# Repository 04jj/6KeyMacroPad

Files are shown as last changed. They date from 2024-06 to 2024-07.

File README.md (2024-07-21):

# 6KeyMacroPad

Feel free to use/modify the files to make your own macropad! ai03's keyboard design wiki is very helpful, I highly recommend reading it.
I am including all PCB files and CAD files for the case. 

Some pics (I 3D printed and sanded the keycaps by hand so they are not the most even/nice):

 

# Specs
* In-key RGB lighting 
* Hot-swappable
* Atmega32U2 MCU
* USB-C Port
* Acrylic stack case
* QMK/VIA compatible

# Firmware/QMK/VIA support
Use zadig to install the WinUSB drivers onto the Atmega32u2
Use qmk msys to compile the .hex file to flash onto the MCU
Use qmk toolbox to flash the MCU (to turn the MCU into bootloader mode, press the reset switch on the back of the PCB)
  - There are default and via keymaps (I recommend using the via one so you can easily map macros/your own keys/adjust lighting easily)

# PCB/Build Files
See folder named PCB Gerber files to get the required files to order the PCB. I did not order PCBA but you can do so if you don't want to hand-solder by referencing the BOM and PCB/Schematic files.

 

For the case, I provided the .step files in the folder named Case Step Files for each layer of the acrylic stack. I used M2 Screws with some washers and spacers to secure everything together (w/o washers M3 screws and spacers should work fine - might require a little bit of sanding).

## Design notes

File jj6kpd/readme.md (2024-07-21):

# jj6kpd

jj6kpd

*A short description of the keyboard/project*

* Keyboard Maintainer: [jj](https://github.com/04jj)
* Hardware Supported: jjkpd pcb or any 2x3 ortho config pcb
* Hardware Availability: from my github page

Make example for this keyboard (after setting up your build environment):

    make jj6kpd:default

* For via support make sure to compile via keymap (to use via go into the design tab and upload via.json to start editing)

Flashing example for this keyboard:

    make jj6kpd:default:flash

See the [build environment setup](https://docs.qmk.fm/#/getting_started_build_tools) and the [make instructions](https://docs.qmk.fm/#/getting_started_make_guide) for more information. Brand new to QMK? Start with our [Complete Newbs Guide](https://docs.qmk.fm/#/newbs).

## Bootloader

Enter the bootloader:

* **Physical reset button**: Briefly press the button on the back of the PCB

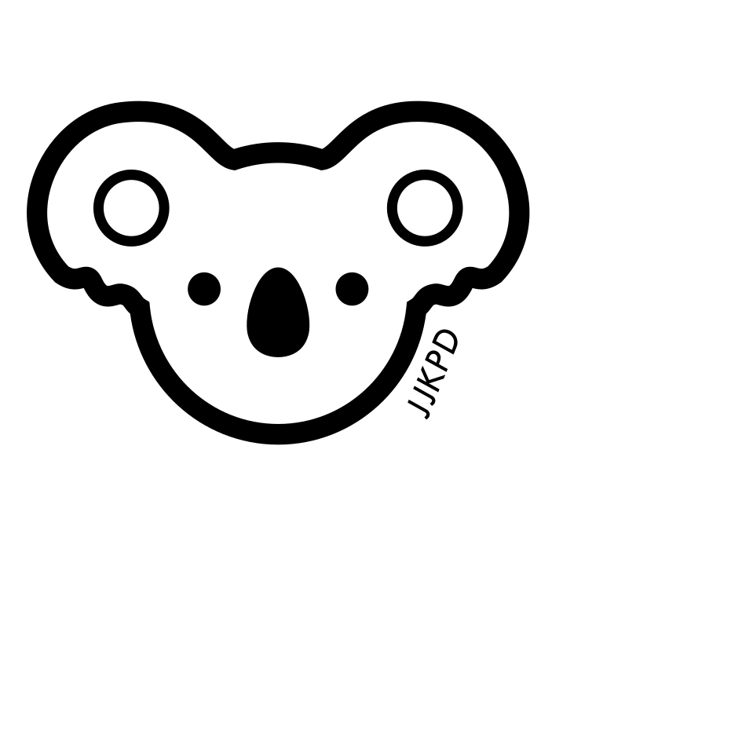
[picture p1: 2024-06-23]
.svg2shenzhen-cache/images/F.SilkS_layer1.png

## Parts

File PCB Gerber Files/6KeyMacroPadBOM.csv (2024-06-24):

Id | Designator | Footprint | Quantity | Designation | Supplier and ref
1 | SW1 | SW_SPST_SKQG_WithStem | 1 | SW_Push
2 | D10,D8,D11,D9,D12,D13 | MX_SK6812MINI-E | 6 | SK6812MINI-E
3 | S6,S2,S5,S3,S4,S1 | Hotswap_MX_1.00u | 6 | Keyswitch
4 | C2,C1 | C_0805_2012Metric | 2 | 22 pF
5 | C5,C4,C6 | C_0805_2012Metric | 3 | 0.1 uF
6 | R3,R4 | R_0805_2012Metric | 2 | 10k
7 | R2,R1 | R_0805_2012Metric | 2 | 22
8 | D7 | SOT-143 | 1 | PRTR5V0U2X
9 | C8,C13,C12,C10,C11,C9 | C_0805_2012Metric | 6 | 100 nF
10 | C3 | C_0805_2012Metric | 1 | 1 uF
11 | R6,R5 | R_0805_2012Metric | 2 | 5.1k
12 | FB1 | L_0805_2012Metric_Pad1.15x1.40mm_HandSolder | 1 | 60@100MHz
13 | Y1 | Crystal_SMD_3225-4Pin_3.2x2.5mm_HandSoldering | 1 | 16 MHz
14 | D4,D5,D3,D6,D1,D2 | D_SOD-123 | 6 | Diode
15 | F1 | Fuse_1206_3216Metric | 1 | 500m
16 | USB1 | HRO-TYPE-C-31-M-12-HandSoldering | 1 | HRO-TYPE-C-31-M-12
17 | C7 | C_0805_2012Metric | 1 | 10 uF
18 | U2 | TQFP-32_7x7mm_P0.8mm | 1 | ATmega32U2-A
19 | R7 | R_0805_2012Metric | 1 | 500
20 | Ref** | jjkpdlogo | 1 | Val**

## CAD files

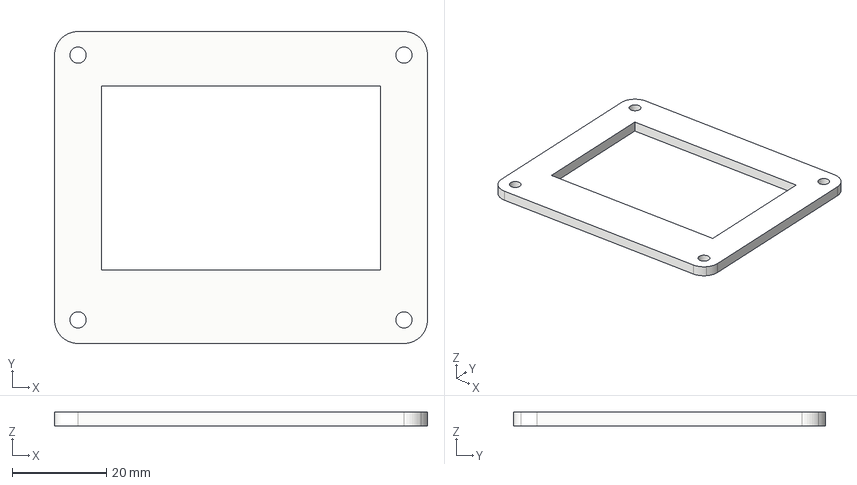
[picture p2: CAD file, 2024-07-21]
Case Step Files/TopPCBCase.step
79.2 x 66.2 x 3.00 mm

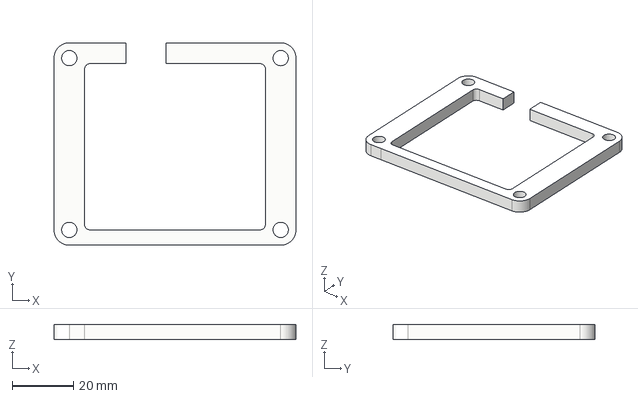
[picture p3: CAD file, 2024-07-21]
Case Step Files/MiddlePCBCase1.step
79.2 x 66.2 x 5.00 mm

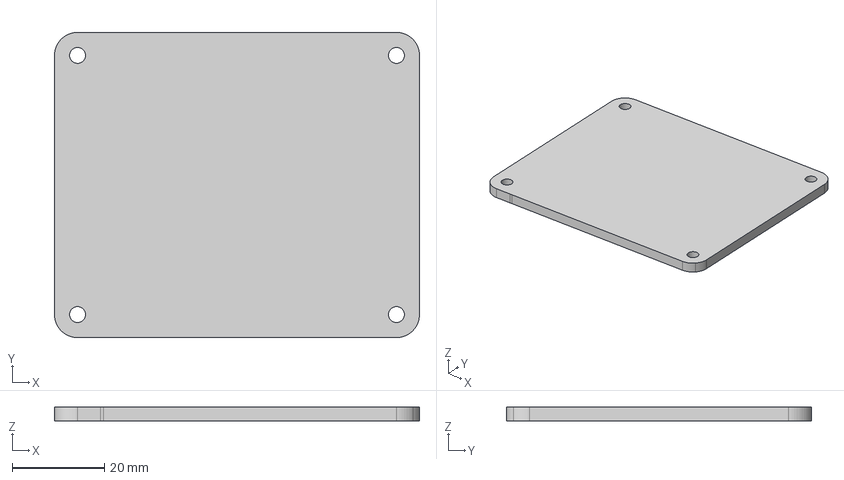
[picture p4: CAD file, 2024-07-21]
Case Step Files/PCBCaseBottom.step
79.2 x 66.2 x 3.00 mm

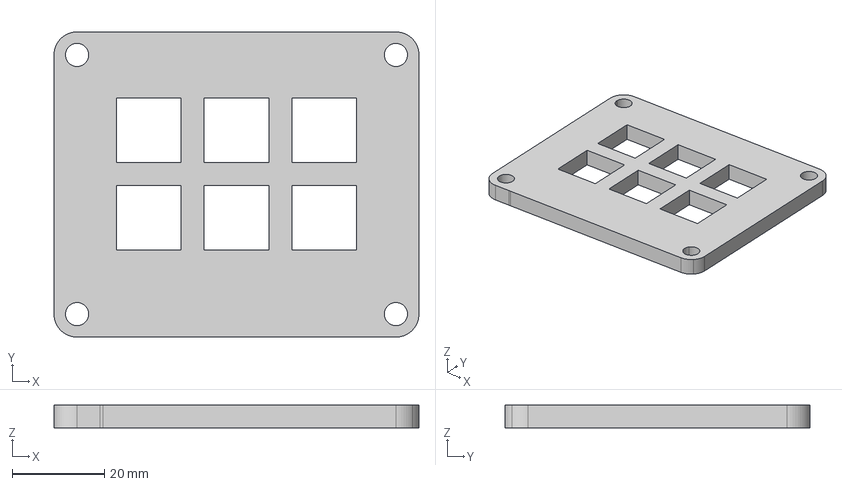
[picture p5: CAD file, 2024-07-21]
Case Step Files/MiddlePCBCase2.step
79.2 x 66.2 x 4.95 mm

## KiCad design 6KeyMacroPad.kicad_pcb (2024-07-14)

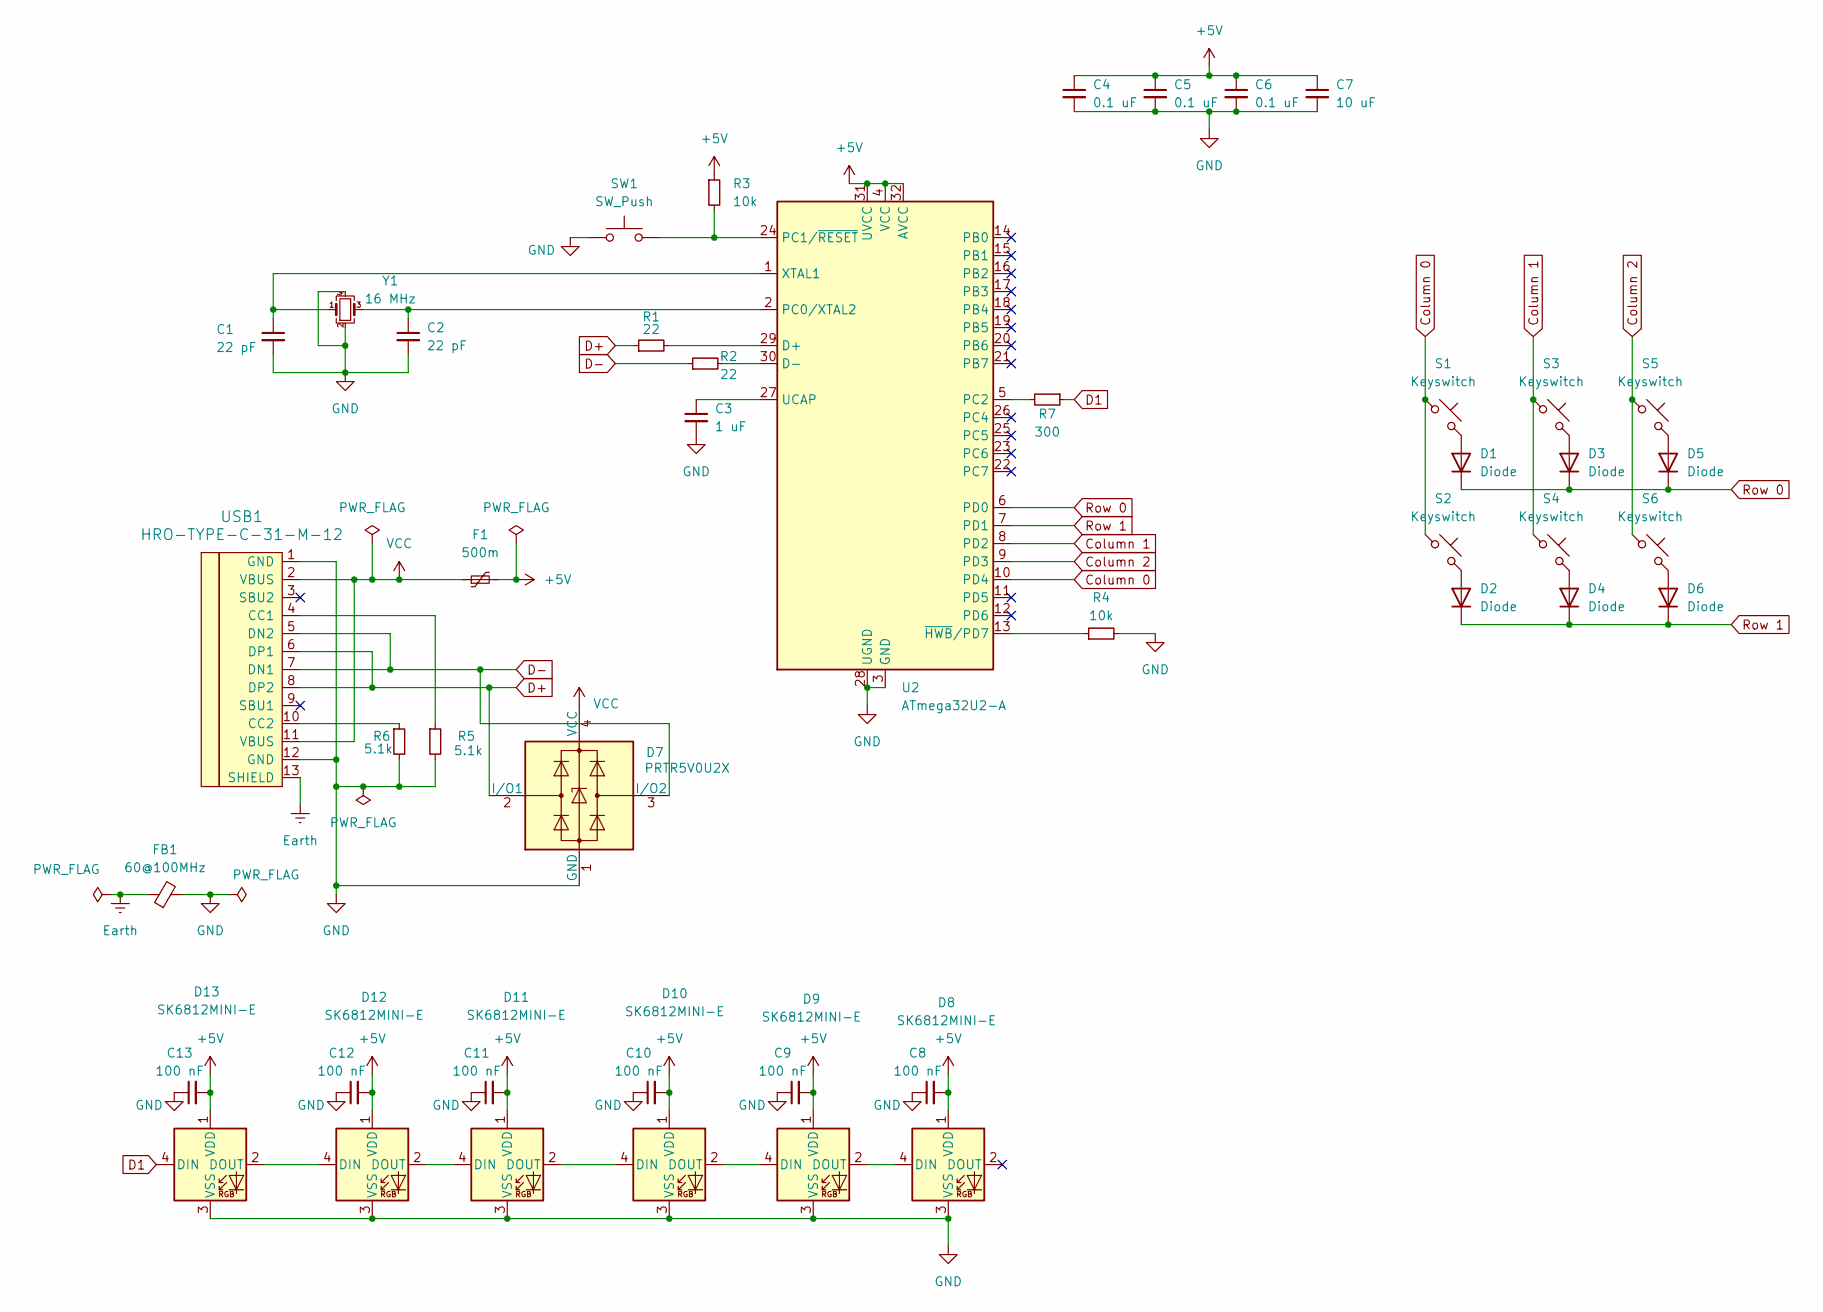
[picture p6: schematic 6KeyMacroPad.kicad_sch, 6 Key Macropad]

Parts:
C1, C2: 22 pF; C_0805_2012Metric
C3: 1 uF; C_0805_2012Metric
C4, C5, C6: 0.1 uF; C_0805_2012Metric
C7: 10 uF; C_0805_2012Metric
C8, C9, C10, C11, C12, C13: 100 nF; C_0805_2012Metric
D1, D2, D3, D4, D5, D6: Diode; D_SOD-123
D7: PRTR5V0U2X; SOT-143
D8, D9, D10, D11, D12, D13: SK6812MINI-E; MX_SK6812MINI-E
F1: 500m; Fuse_1206_3216Metric
FB1: 60@100MHz; L_0805_2012Metric_Pad1.15x1.40mm_HandSolder
R1, R2: 22; R_0805_2012Metric
R3, R4: 10k; R_0805_2012Metric
R5, R6: 5.1k; R_0805_2012Metric
R7: 300; R_0805_2012Metric
S1, S2, S3, S4, S5, S6: Keyswitch; Hotswap_MX_1.00u
SW1: SW_Push; SW_SPST_SKQG_WithStem
U2: ATmega32U2-A; TQFP-32_7x7mm_P0.8mm
USB1: HRO-TYPE-C-31-M-12; HRO-TYPE-C-31-M-12-HandSoldering
Y1: 16 MHz; Crystal_SMD_3225-4Pin_3.2x2.5mm_HandSoldering

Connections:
+5V: C4.1, C5.1, C6.1, C7.1, C8.2, C9.2, C10.2, C11.2, C12.2, C13.2, D8.1 (VDD), D9.1 (VDD), D10.1 (VDD), D11.1 (VDD), D12.1 (VDD), D13.1 (VDD), F1.2, R3.1, U2.4 (VCC), U2.31 (UVCC), U2.32 (AVCC)
Column 0: S1.1, S2.1, U2.10 (PD4)
Column 1: S3.1, S4.1, U2.8 (PD2)
Column 2: S5.1, S6.1, U2.9 (PD3)
D1: D13.4 (DIN), R7.1
D+: D7.2 (I/O1), R1.1, USB1.6 (DP1), USB1.8 (DP2)
D-: D7.3 (I/O2), R2.1, USB1.5 (DN2), USB1.7 (DN1)
Earth: FB1.1, USB1.13 (SHIELD)
GND: C1.2, C2.2, C3.2, C4.2, C5.2, C6.2, C7.2, C8.1, C9.1, C10.1, C11.1, C12.1, C13.1, D7.1 (GND), D8.3 (VSS), D9.3 (VSS), D10.3 (VSS), D11.3 (VSS), D12.3 (VSS), D13.3 (VSS), FB1.2, R4.2, R5.2, R6.2, SW1.1, U2.3 (GND), U2.28 (UGND), USB1.1 (GND), USB1.12 (GND), Y1.2, Y1.4
unnamed: D1.2 (A), S1.2
unnamed: D2.2 (A), S2.2
unnamed: D3.2 (A), S3.2
unnamed: D4.2 (A), S4.2
unnamed: D5.2 (A), S5.2
unnamed: D6.2 (A), S6.2
unnamed: D8.4 (DIN), D9.2 (DOUT)
unnamed: D10.4 (DIN), D11.2 (DOUT)
unnamed: D9.4 (DIN), D10.2 (DOUT)
unnamed: D11.4 (DIN), D12.2 (DOUT)
unnamed: D12.4 (DIN), D13.2 (DOUT)
unnamed: R1.2, U2.29 (D+)
unnamed: R2.2, U2.30 (D-)
unnamed: C2.1, U2.2 (PC0/XTAL2), Y1.3
unnamed: R3.2, SW1.2, U2.24 (PC1/~RESET)
unnamed: R7.2, U2.5 (PC2)
unnamed: C3.1, U2.27 (UCAP)
unnamed: C1.1, U2.1 (XTAL1), Y1.1
unnamed: R4.1, U2.13 (~HWB/PD7)
unnamed: R5.1, USB1.4 (CC1)
unnamed: R6.1, USB1.10 (CC2)
Row 0: D1.1 (K), D3.1 (K), D5.1 (K), U2.6 (PD0)
Row 1: D2.1 (K), D4.1 (K), D6.1 (K), U2.7 (PD1)
VCC: D7.4 (VCC), F1.1, USB1.2 (VBUS), USB1.11 (VBUS)

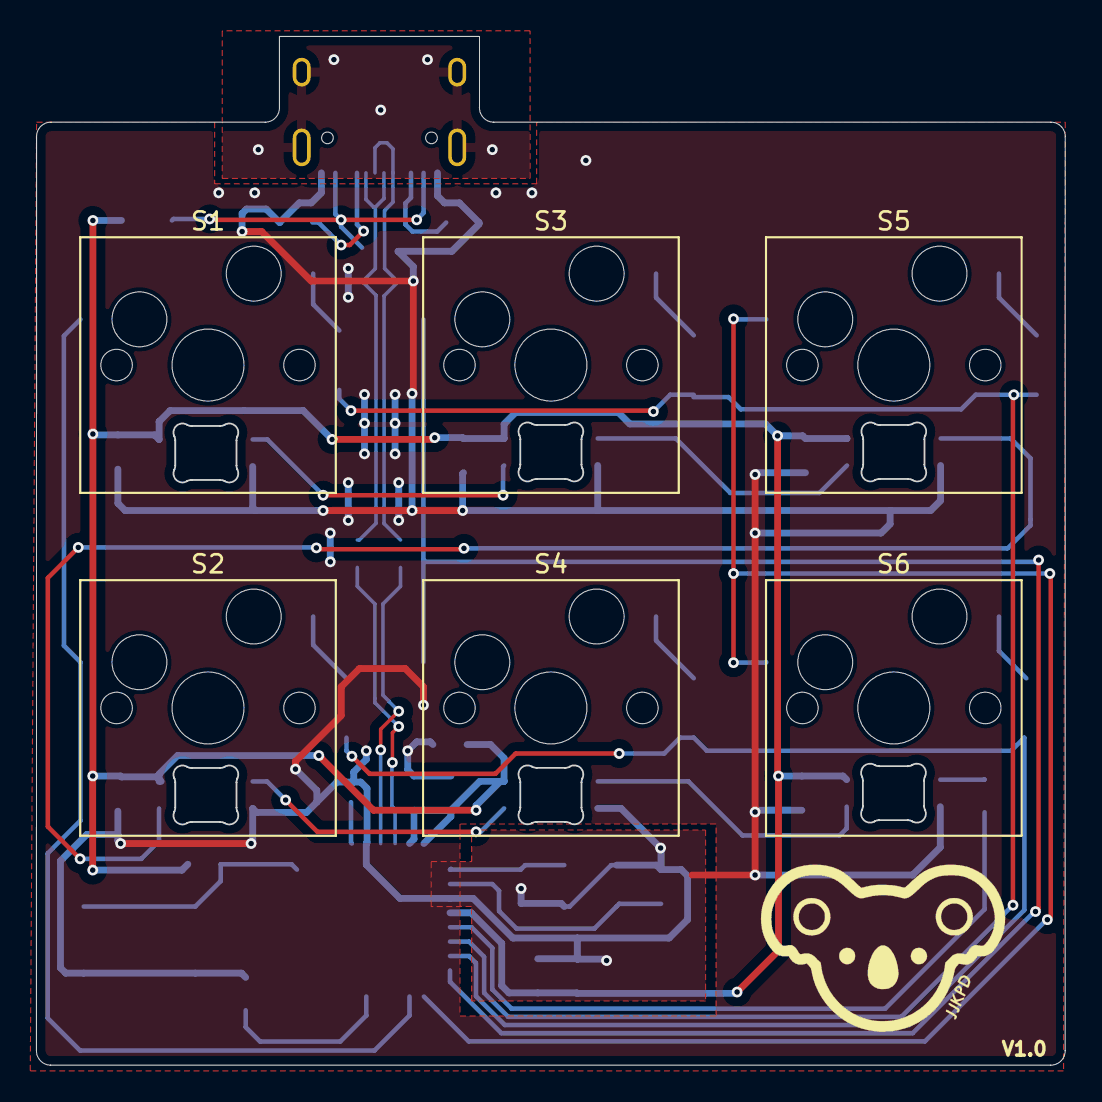
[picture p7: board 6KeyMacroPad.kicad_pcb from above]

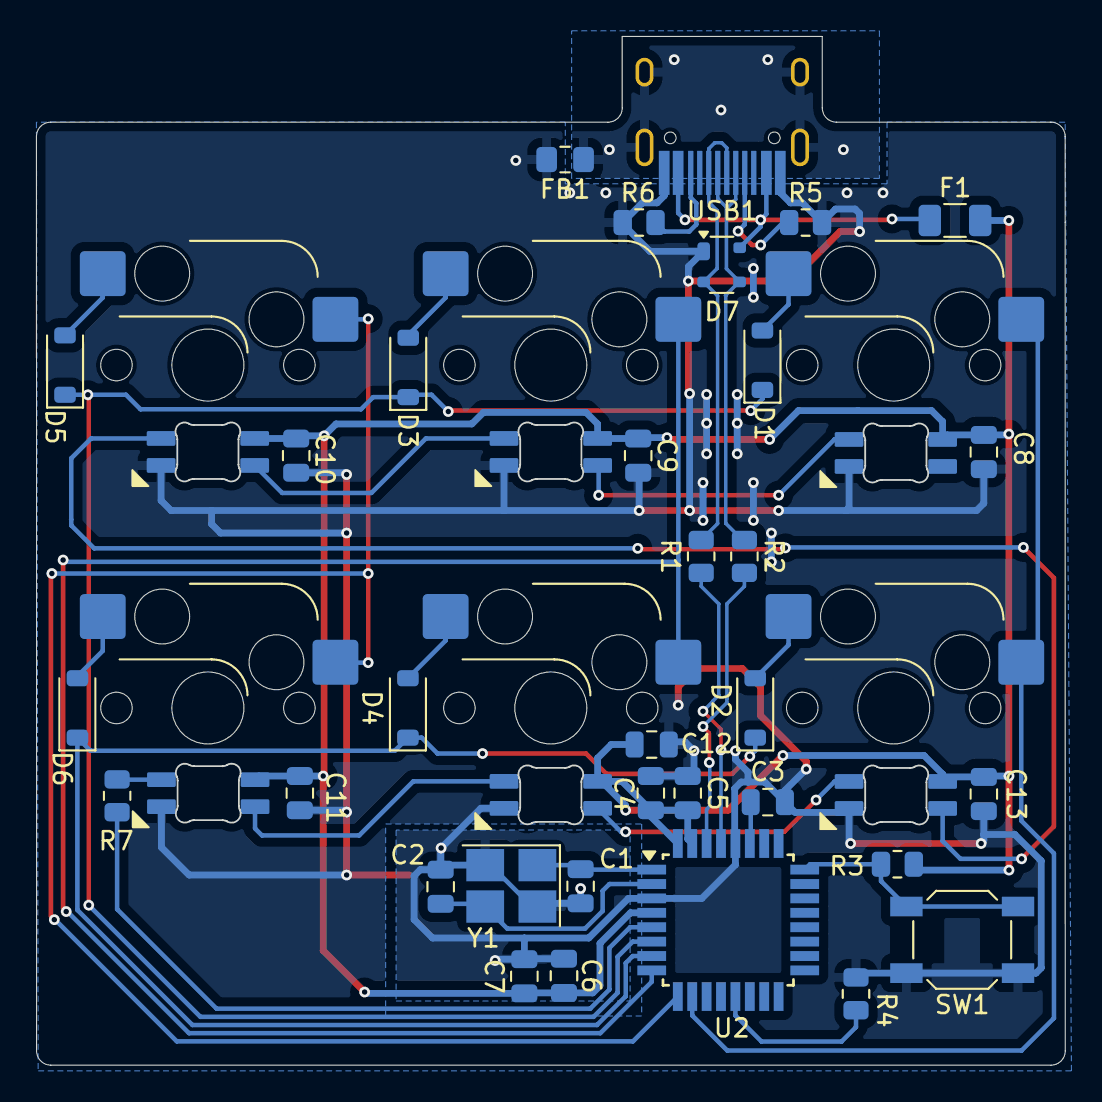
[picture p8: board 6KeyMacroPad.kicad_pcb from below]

Board: 2 copper layers, 57.2 x 57.1 mm, 46 parts (33 on the bottom side), 33 nets.

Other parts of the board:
Ref**: Val**; jjkpdlogo

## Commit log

2024-05-27 schematic updates
    - added WS2812B leds
    - added ESD: PRTR5V0U2X, USB 2.0 Type-C connector: HRO-TYPE-C-31-M12
    - ERC checked
    [6KeyMacroPad.kicad_pcb, 6KeyMacroPad.kicad_sch]
2024-05-31 assign footprints
    [6KeyMacroPad.kicad_pcb, 6KeyMacroPad.kicad_sch]
2024-06-01 board layout updates
    [6KeyMacroPad.kicad_pcb, 6KeyMacroPad.kicad_sch]
2024-06-23 footprint edits, routing updates
    drc checked
    [6KeyMacroPad.kicad_pcb, 6KeyMacroPad.kicad_sch]
2024-06-24 manufacturing files changed
    [6KeyMacroPad-B_Cu.gbr, 6KeyMacroPad-B_Mask.gbr, 6KeyMacroPad-B_Silkscreen.gbr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]
2024-07-14 add qmk/via support
    [6KeyMacroPad.kicad_pcb]
2024-07-21 Add step files, firmware updates, organizing files
    [6KeyMacroPad-B_Cu.gbr, 6KeyMacroPad-B_Mask.gbr, 6KeyMacroPad-B_Silkscreen.gbr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]
